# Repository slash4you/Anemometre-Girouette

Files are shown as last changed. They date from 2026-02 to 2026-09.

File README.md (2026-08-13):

# Anémomètre+Girouette
Projet de construction DIY d'un anémomètre et d‘ une girouette connectés à Home Assistant.

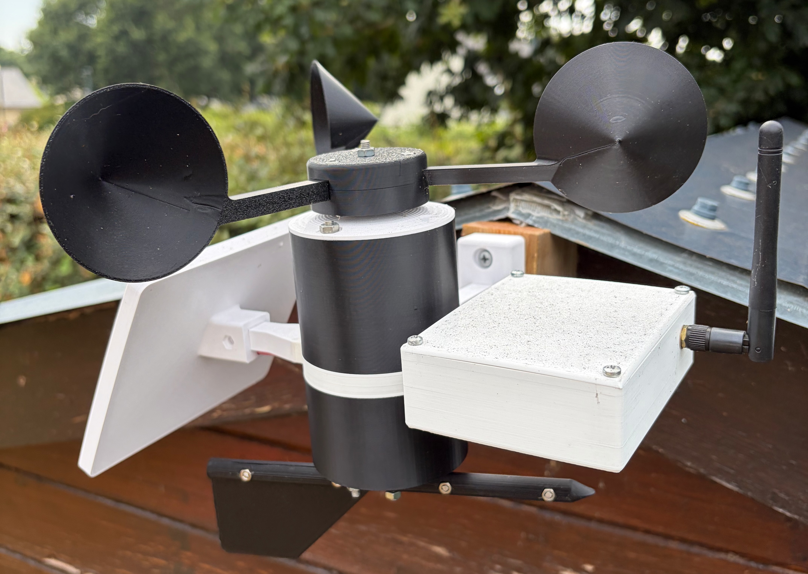
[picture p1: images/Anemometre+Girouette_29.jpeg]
Installation
 

## Caractéristiques principales 
|  | DIY | Conception |
|---|---|---|
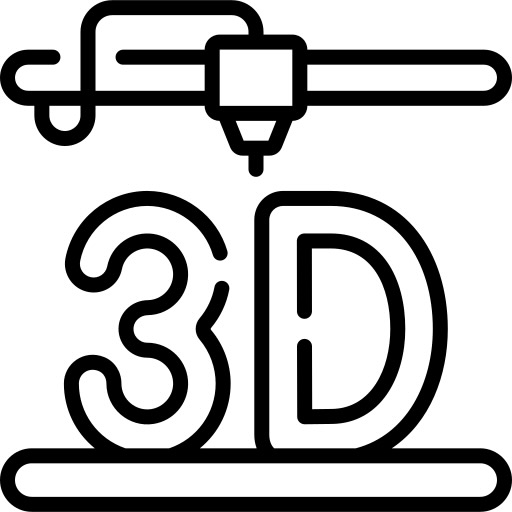
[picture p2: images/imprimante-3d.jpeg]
Imprimante 3D
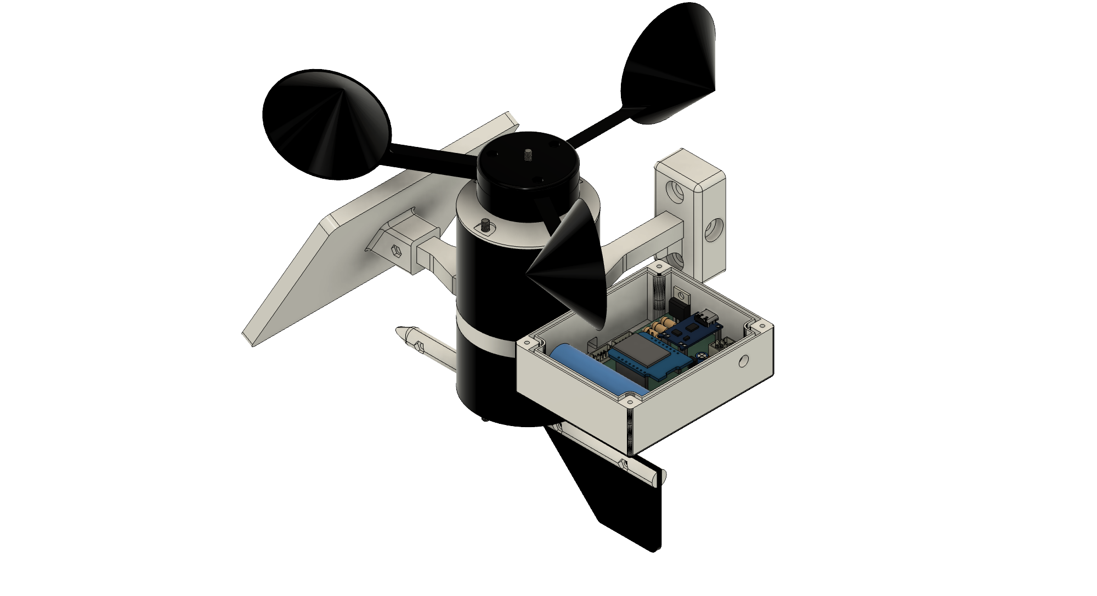
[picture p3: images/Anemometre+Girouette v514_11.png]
Modèle 3D
|  | 100% imprimable (PETG ou ABS, TPU), compacte, alimentation par batterie 18650 au Lithium (3800mAh) , recharge par panneau solaire (2W), mesure de la vitesse du vent par capteur à effet hall, mesure de la direction du vent (en cours)  |   |
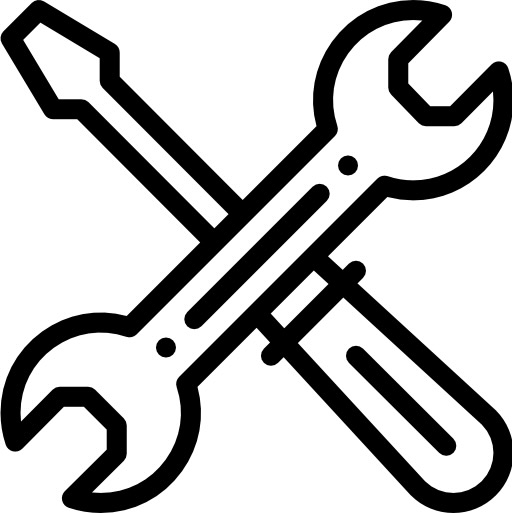
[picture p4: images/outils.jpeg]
Outils
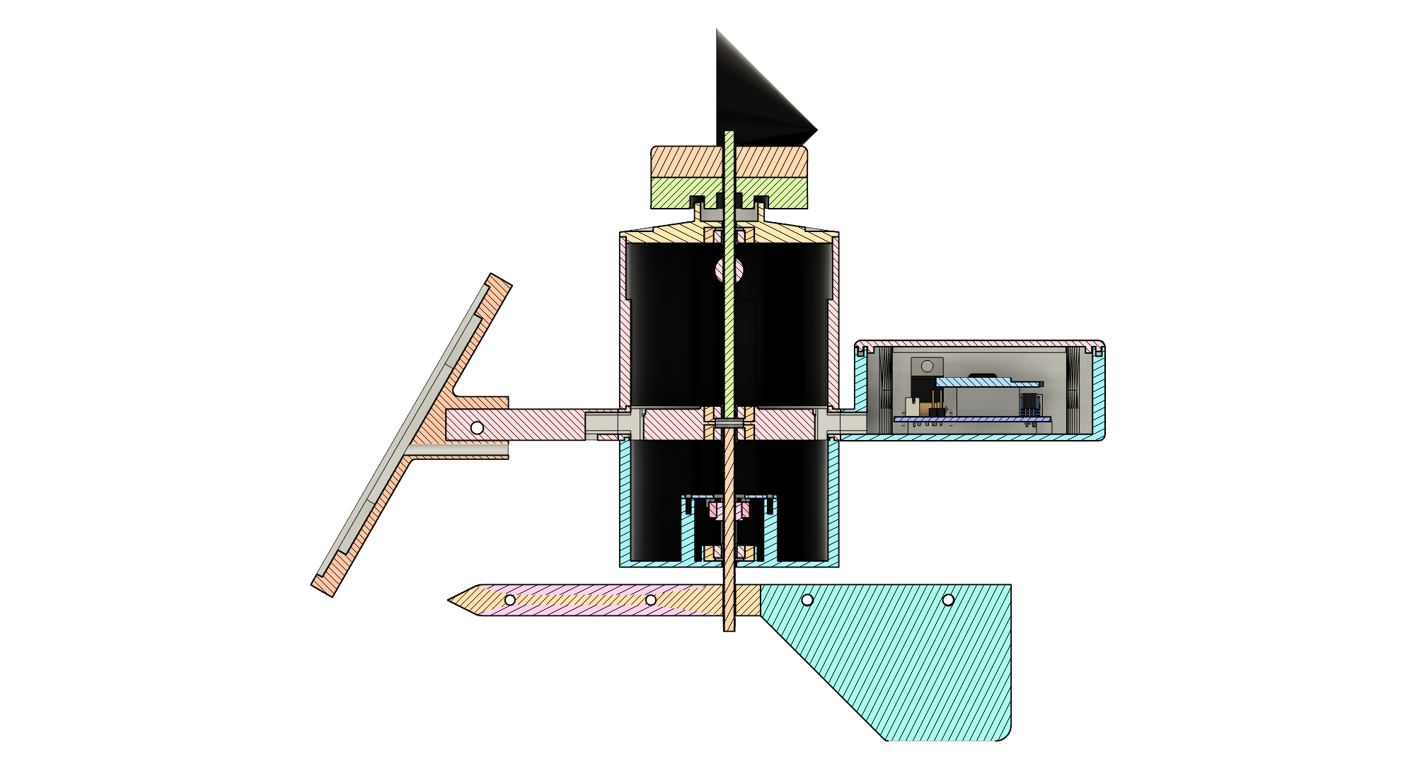
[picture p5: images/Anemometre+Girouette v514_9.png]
Modèle 2D
|  | assemblage par visserie standard, colle au silicone (étanchéité de la boite de commande), colle cyanoacrylate (selon l‘ ajustement des queues d‘ arronde) |   |
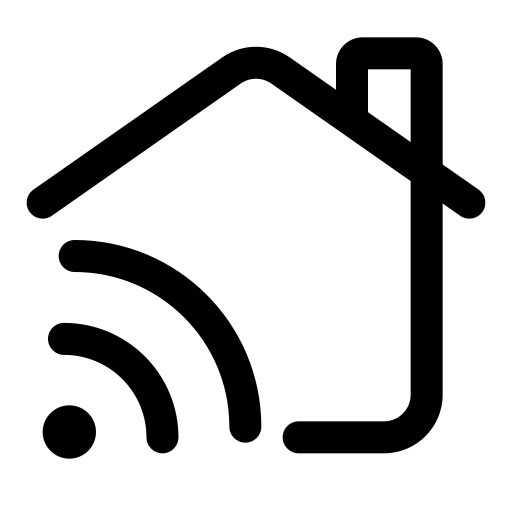
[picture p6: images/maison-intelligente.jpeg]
Domotique
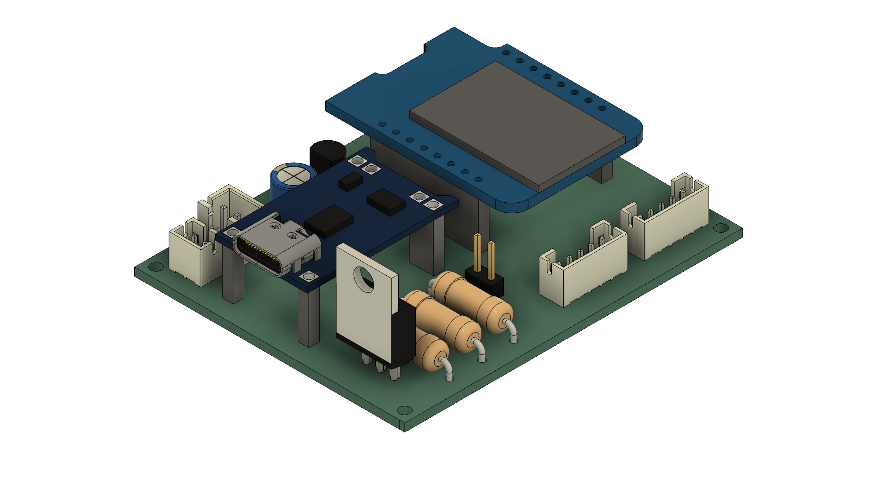
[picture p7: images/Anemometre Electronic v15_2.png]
|  | composants low-cost, firmware opensource, connection WIFI au serveur domotique, esphome ready, optimisation de l‘ autonomie |   |
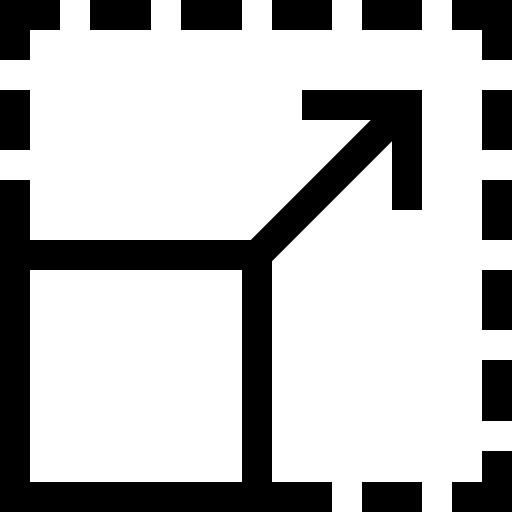
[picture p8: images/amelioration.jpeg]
Evolution
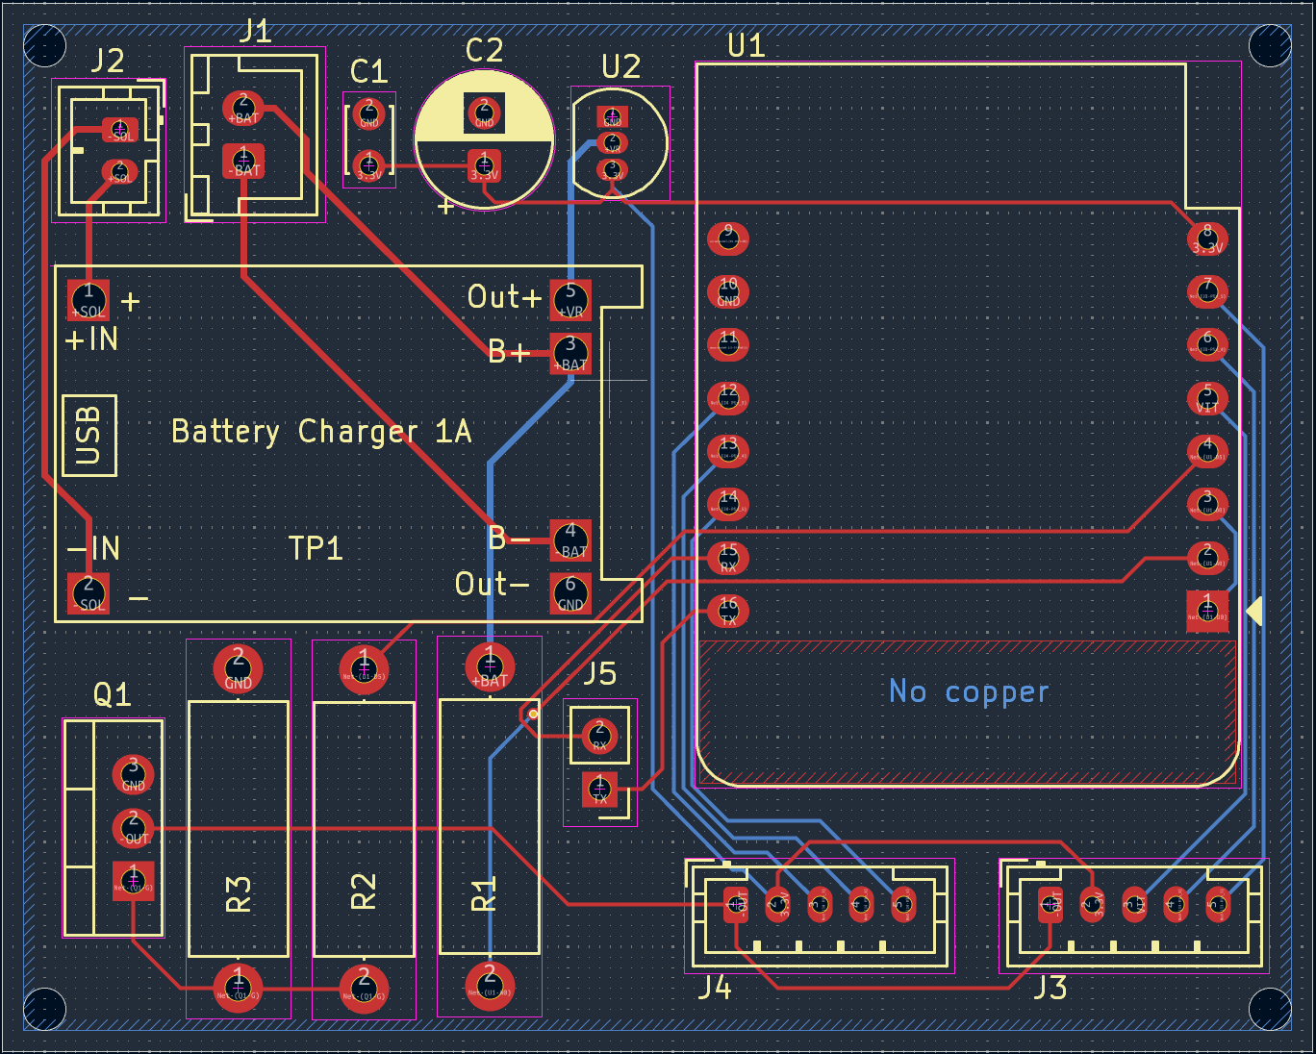
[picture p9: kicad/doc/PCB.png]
PCB
|  | conception modifiable, évolutive, toutes les données partagées, personnalisable à volonté |   |

## GitHub

Ce dépôt regroupe l‘ ensemble des données nécessaires à la construction de cet anémomètre, organisées de la façon suivante:
+ [fusion360](https://github.com/slash4you/Anemometre-Girouette/blob/main/fusion360) → contient le modèle 3D au format f3d
+ [bambustudio](https://github.com/slash4you/Anemometre-Girouette/blob/main/bambustudio) → contient le modèle d ‘impression au format 3mf
+ [stl](https://github.com/slash4you/Anemometre-Girouette/blob/main/stl) → contient le fichier de maillage de chaque composant au format stl
+ [esphome](https://github.com/slash4you/Anemometre-Girouette/blob/main/esphome) → contient la description du firmware au format yaml
+ [images](https://github.com/slash4you/Anemometre-Girouette/blob/main/images) → contient un ensemble d ‘ images du modèle et photos du prototype
+ [kicad](https://github.com/slash4you/Anemometre-Girouette/blob/main/kicad)  → contient la définition du PCB au format kicad et gerber

## Makerworld

Le projet d‘ impression correspondant est disponible ici:  [Anémomètre+Girouette](https://makerworld.com/fr/models/2154241) .

## Avancement

Le premier objectif est la mise au point d‘ un prototype fonctionnel (version beta du projet), avant de capitaliser les informations et formaliser la documentation indispensable à une diffusion plus large (version release du projet). 

> Pour les impatients sachez que ce n ‘est pas l‘ envie qui fait défaut mais bien le temps... d‘ autant qu‘ il s‘ agit de ma première expérience en modélisation 3D, en conception de PCB, et que l‘ impression 3D est une expérience très récente. Toute aide est la bienvenue pour corriger, améliorer, tester.. bref partager.

### 1. Version beta (V0) : prototypage

- [x] 100%  : modélisation de la structure mécanique
- [x] 100%  : approvisionnement des composants tierces
- [x] 100%  : impression+assemblage de la structure mécanique
- [x] 100%  : assemblage des composants électroniques ( panneau solaire + calculateur + batterie + CI )
- [x] 100%  : développement du firmware du calculateur
- [x] 100% : intégration des capteurs de mesure de l‘ anémomètre
- [x] 100% : 🍾
- [x] 100% : intégration des capteurs de mesure de la girouette
- [x] 100% : 🍾
- [x] 100% : tests en environnement réel
- [x] 100% : 🎉

| | Réalisation |
|---|---|
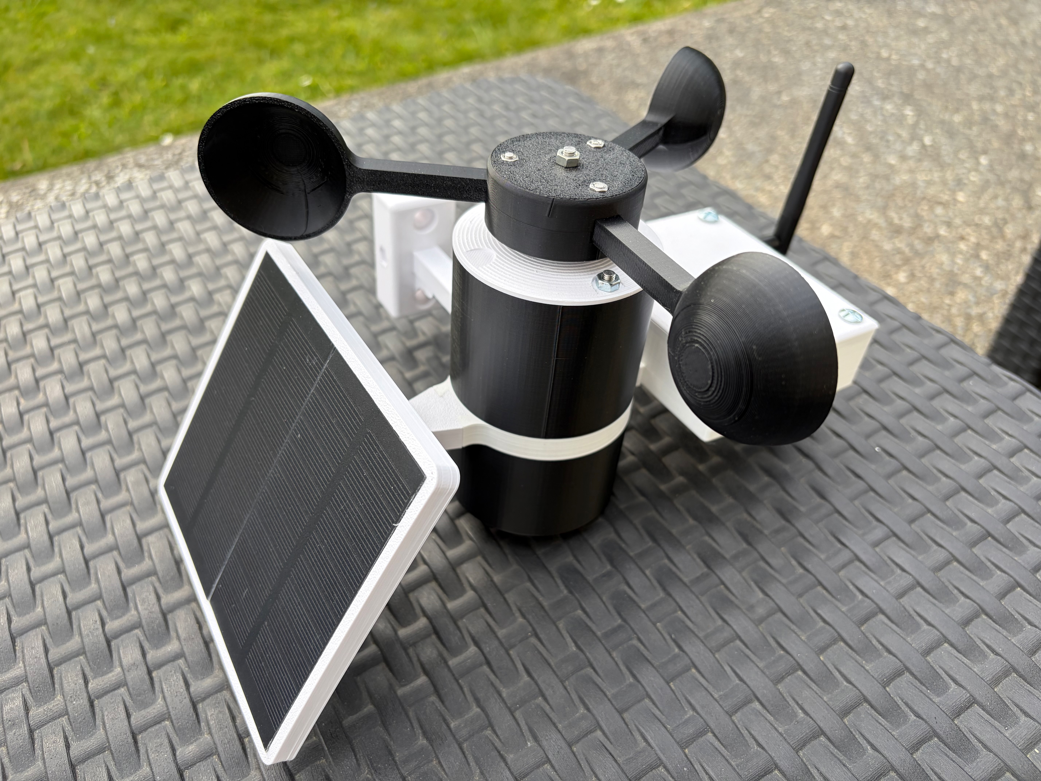
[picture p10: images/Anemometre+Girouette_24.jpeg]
Prototype
| Imprimante 3D |  |
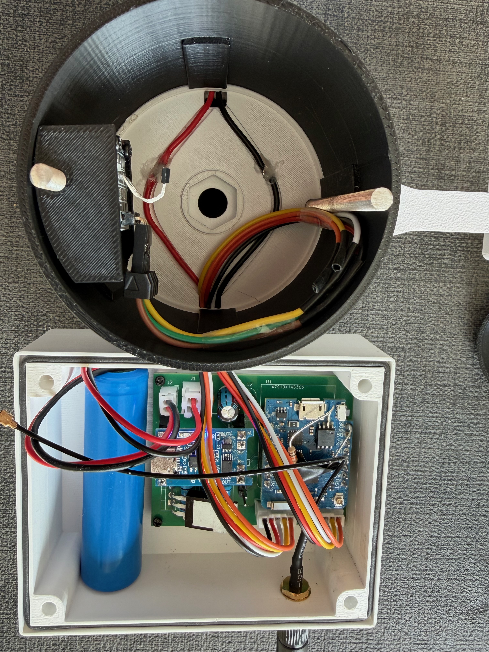
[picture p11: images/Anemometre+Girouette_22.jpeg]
Assemblage
| Outils |  |
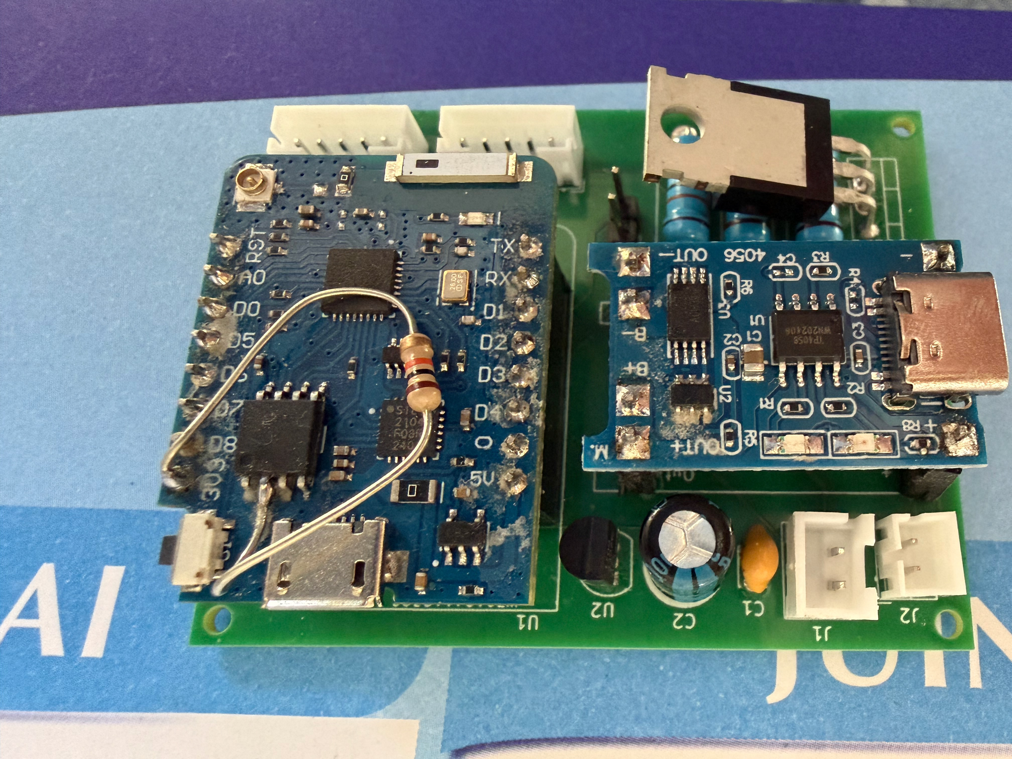
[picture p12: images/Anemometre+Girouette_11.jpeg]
| Domotique | |

### 2. Retours d‘ expérience sur le prototype après 1 mois

Après un mois d‘ installation dans le jardin, l‘ heure des premiers retours sur l‘ anémomètre DIY est arrivée :

#### Étanchéité de la boite de commande
Même si j‘ avais anticipé cette problématique lors de la conception, l‘ étanchéité du design initial n‘ était pas au rendez-vous puisqu‘ une semaine de pluie continue a complètement noyé la boite de commande. L‘ électronique et l‘ eau n‘ ont pas fait bon ménage et un des roulements s‘ est même oxydé jusqu‘ au blocage de la rotation de l‘ axe de l‘ anémomètre.
Une mise à jour de la boite de commande et de son couvercle a résolu ce problème.

#### Sensibilité par vent faible
J‘ avais privilégié la robustesse comme profil d‘ impression, craignant une fragilité des éléments imprimés lors des fortes rafale de vent assez fréquentes dans notre région. Mais je n‘ avais pas anticipé que l‘ inertie induite par cet excédent de matière aurait une conséquence sur la sensibilité par vent faible.
Une mise à jour de la forme et de la masse des coupelles a légèrement amélioré ce point mais l‘ inertie devra encore être optimisée et les frottements lors de la rotation devront être diminués pour obtenir un résultat convenable.
En l‘ état les coupelles se mettent en mouvement à partir de 10km/h de vent environ. Ceci se visualise parfaitement dans l‘ historisation des mesures par des tranches temporelles à 0 km/h car la période actuelle est très peu ventée ( vitesse moyenne locale issue d‘ internet comprise entre 5km/h et 15km/h.

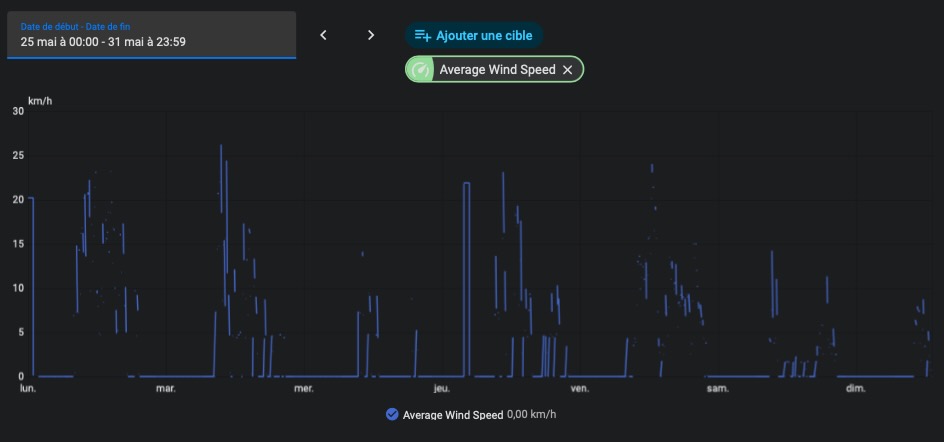
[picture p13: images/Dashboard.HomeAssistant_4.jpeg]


Parmi les axes d‘ amélioration :
* optimiser les dimensions et le taux de remplissage des éléments mobiles.
* améliorer le montage des roulements, voire le choix du nombre et du type de roulements pour limiter les frottements à la rotation.

#### Calibration RPM vs km/h
J‘ avais sous-estimé la problématique de calibration pour obtenir une estimation fiable de la vitesse du vent à partir de la vitesse de rotation de l‘ anémomètre. Cette problématique est d‘ autant plus exagérée dans mon cas que :
- le seul site d‘ installation dans mon jardin est trop protégé des vents.
- je suspecte que la compacité souhaitée pour cet anémomètre n‘ est pas idéal pour obtenir un flux d‘ air « laminaire », ou à minima le moins perturbé possible, indispensable pour des mesures fiables.

Pour l‘ instant je compense ceci par une table de calibration qui maximise exagérément les mesures, mais cette technique n‘ est pas viable pour un résultat convenable et surtout pas transposable pour quiconque utiliserait le firmware dans son contexte.

Monitoring

#### Électronique
L‘ électronique, et en particulier la gestion de l‘ énergie, sont en revanche une bonne surprise du projet. 
La stabilité de la communication avec le serveur domotique est au rendez-vous et la gestion de la charge de la batterie par le panneau solaire donne des résultats qui confirme la viabilité de la solution. 
Ce constat n‘ est sans doute pas étranger au fait que cette activité du projet est dans mes compétences.

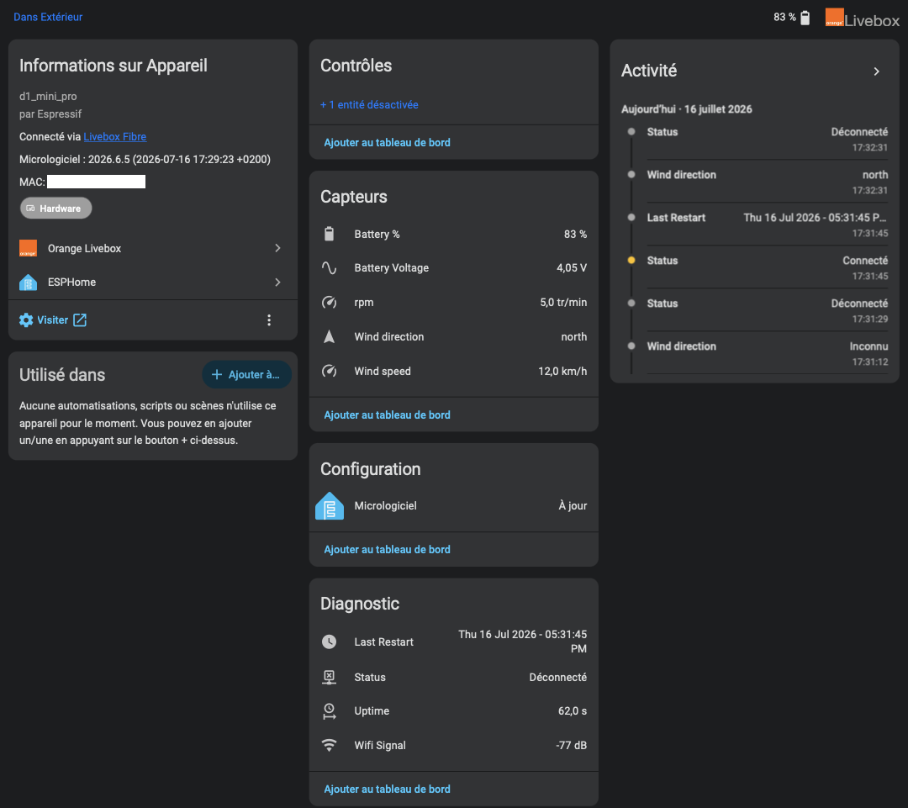
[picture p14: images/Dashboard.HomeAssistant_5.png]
Dashboard
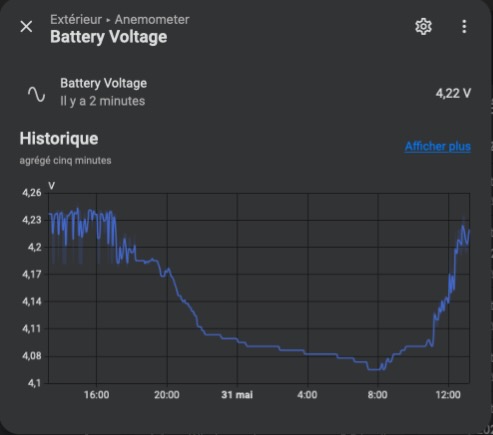
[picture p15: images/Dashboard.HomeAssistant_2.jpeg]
      

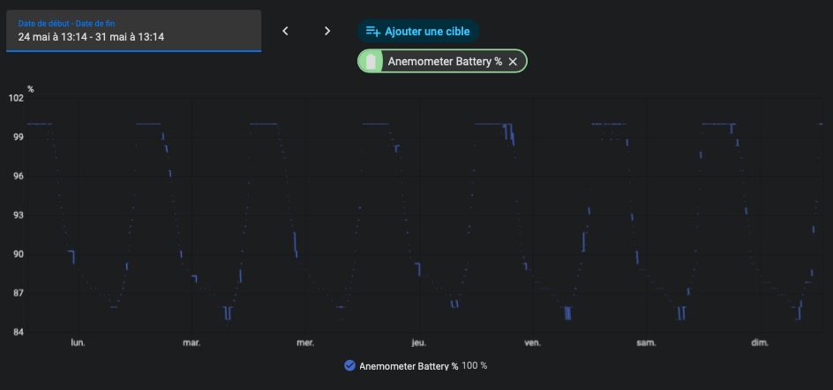
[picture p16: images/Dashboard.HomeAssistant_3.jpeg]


#### Assemblage
La complexité de l‘ assemblage révèle mon inexpérience en matière de conception 3D. Il est évident que le montage pourrait être largement simplifié par une meilleure conception, le nombre de pièces et le volume de matière imprimable pourraient être rationalisés, et par conséquent le coût global de la solution optimisé.
Parmi les axes d‘ amélioration :
* simplifier le montage des roulements pour limiter le nombre de pièces, la nécessité d‘ un parallélisme entre-eux, ...
* rendre indépendant la fixation du corps de la girouette de celle de l‘ anémomètre.
* utiliser un matériau transparent pour certaines pièces.

### 3. Retours d‘ expérience sur le prototype après 3 mois

Après trois mois d‘ installation dans le jardin, de nouvelles conclusions s‘ imposent :

#### Sensibilité par vent faible

La sensibilité de l‘ anémomètre a grandement été améliorée par un ajustement non contraint de l‘ un des 2 paliers de roulement pour chaque axe, libérant les contraintes axiales et contribuant ainsi à :
* simplifier globalement l‘ assemblage : moins de précision nécessaire au réglage de la longueur entre roulements,  fermeture facilitée par une insertion de l‘ extrémité opposée plus libre.
* augmenter de façon significative la sensibilité par vent faible, jusqu‘ à atteindre la vitesse de marche, soit environ 5 km/h.
Je considère que la mise à jour de ces ajustements a complètement résolu ce problème.

#### Pas de codage de la mesure de direction

J‘ envisageais initialement une conception permettant la mesure de 8 directions par la girouette, mais le prix unitaire pour coder 8 pas m‘ a semblé disproportionné. J‘ ai donc réduit cette spécification à 4 directions seulement pour limiter le coût global de la solution.

#### Stabilité de fonctionnement

Le montage est finalement achevé et fonctionnel, et la stabilité de fonctionnement sur la période est plus que satisfaisante. Un seul bug a été observé en 3 mois d‘ utilisation, nécessitant un reboot manuel du microcontrôleur pour palier à une absence de réveil (i.e. sortie du deep-sleep). Je n‘ ai pas beaucoup d‘ informations pour en analyser la cause car le problème est apparu au milieu de la nuit et avec toutes les traces logicielles désactivées. Mais je ne pense pas que le hardware soit en cause.  
A ce stade je mets plutôt en doute un problème introduit par une mise à jour d‘ esphome qui a souvent évolué sur la période et de manière significative.

#### Précisions des mesures

En toute transparence la précision des mesures est en-deçà de ce que j‘ espérais initialement. Un travail supplémentaire devra être mené sur :
* le site d‘ installation (problème spécifique à mon contexte)
* la calibration des mesures de vitesse de vent
* le lissage de la direction du vent par intégration dans le temps

### 4. Retours d‘ expérience sur le prototype après 4 mois

#### Précisions des mesures

Pour améliorer la précision des mesures, une variante du support mural a été conçue pour diminuer les perturbations dans la circulation des masses d‘ air.

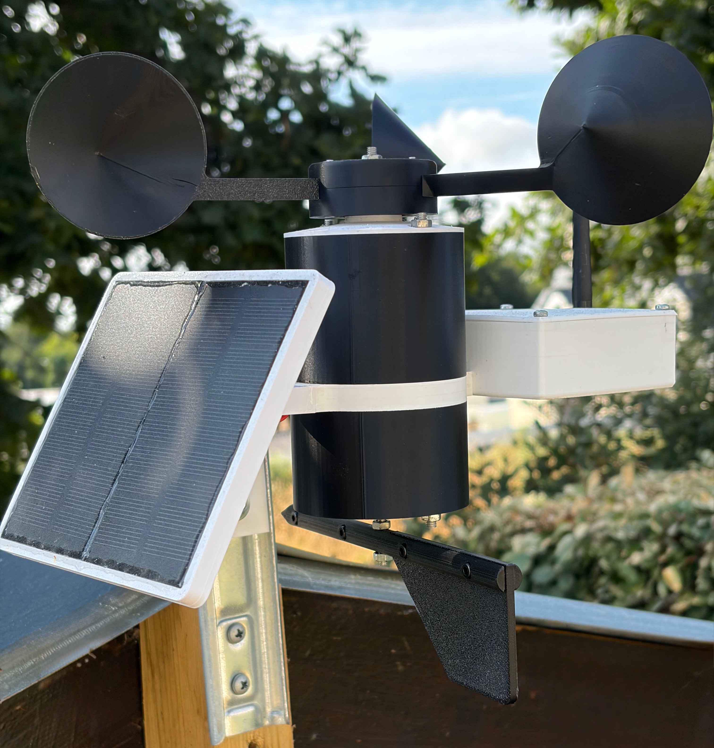
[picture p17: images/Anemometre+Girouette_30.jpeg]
Nouveau support
 

Ce nouveau support améliore un peu la précision des mesures, et en particulier la direction du vent, mais ne corrige pas le problème de fond de mon installation, la présence d‘ arbres à proximité dans toutes les directions .

### 5. Version release (V1) : partage et support

- [ ]    0%  : étalonnage des mesures et optimisation de leur durée d‘ intégration
- [ ]    0%  : optimisation de la charge en fonction de l‘ ensoleillement, de la saison, de l‘ heure, ...
- [ ]    0%  : publication d‘ un profil d‘ impression makerworld « plug-and-play »
- [x] 100%  : documentation/schéma électronique/inventaire des composants électroniques
- [ ]    0%  : documentation/inventaire des composants mécaniques
- [ ]    0%  : documentation/tutoriel de montage

#### Documentation

TODO

#### Inventaire des composants/matériaux

Pour quiconque se lancerait dans la construction, voici la liste des composants pour le PCB  :
| N° | Référence | Valeur/Modèle | Désignation |
|---|---|---|---|
| 1 | C1 | 100nF | [C_Disc_D3.0mm_W2.0mm_P2.50m](https://fr.aliexpress.com/item/32973259342.html) |
| 2 | C2 | 100µF | [CP_Radial_D6.3mm_P2.50mm](https://fr.aliexpress.com/item/1005002524973878.html) |
| 3 | R1 | 120KΩ | [R_Axial_DIN0414_L11.9mm_D4.5mm_P15.24mm_Horizontal](https://fr.aliexpress.com/item/1005007032692303.html) |
| 4 | R2 | 330Ω | [R_Axial_DIN0414_L11.9mm_D4.5mm_P15.24mm_Horizontal](https://fr.aliexpress.com/item/1005007032692303.html) |
| 5 | R3 | 120KΩ | [R_Axial_DIN0414_L11.9mm_D4.5mm_P15.24mm_Horizontal](https://fr.aliexpress.com/item/1005007032692303.html) |
| 6 | U1 | WeMos D1 mini pro | [WEMOS_D1_mini_light](https://fr.aliexpress.com/item/1005007475726143.html) |
| 7 | U2 | MCP1700-330 TO-92 | [TO-92_Inline](https://fr.aliexpress.com/item/1005007167297693.html) |
| 8 | Q1 | IRLZ44N TO-220 | [TO-220-3_Vertical](https://fr.aliexpress.com/item/1005007174659364.html) |
| 9 | TP1 | TP4056 USB-C | [TP4056_module](https://fr.aliexpress.com/item/1005006124994712.html) |
| 10 | J1 | XH2.54-2P | [JST_XH_B2B-XH-A_1x02_P2.50mm_Vertical](https://fr.aliexpress.com/item/1005004985397880.html) |
| 11 | J2 | PH2.0-2P | [JST_PH_B2B-PH-K_1x02_P2.00mm_Vertical](https://fr.aliexpress.com/item/1005007441813591.html) |
| 12 | J3 | PH2.0-5P | [JST_PH_B5B-PH-K_1x05_P2.00mm_Vertical](https://fr.aliexpress.com/item/1005007441813591.html) |
| 13 | J4 | PH2.0-5P | [JST_PH_B5B-PH-K_1x05_P2.00mm_Vertical](https://fr.aliexpress.com/item/1005007441813591.html) |
| 14 | J5 | XH2.54-2P | [PinHeader_1x02_P2.54mm_Vertical](https://fr.aliexpress.com/item/4000988113226.html) |

La liste des composants pour l‘ alimentation :
| N° | Qté | Valeur/Modèle | Désignation |
|---|---|---|---|
| 1 | 1| 18650 Lithium 3.7V 3800mAh XH2.54-2P | [Batterie Lithium](https://fr.aliexpress.com/item/1005007257546981.html)|
| 2 | 2| 5V 1W 107x61mm| [Panneaux solaires](https://fr.aliexpress.com/item/1005006711306491.html)|

La liste des composants pour les mesures :
| N° | Qté | Valeur/Modèle | Désignation |
|---|---|---|---|
|  1 | 1| KY-003 A3144| [Capteur à effet hall](https://fr.aliexpress.com/item/1005007985856987.html) |
|  2  | 2 | Disque 5x3mm | [Aimants ferrite](https://fr.aliexpress.com/item/1005008858265927.html) |
| 3  |  1 | STM8-P4 | [Capteur magnétique  de direction](https://fr.aliexpress.com/item/1005004379591016.html) |

La liste des consommables pour l‘ impression 3D :
| N° | Qté | Valeur/Modèle | Désignation |
|---|---|---|---|
|  1 | NNNg| PETG HF| [blanc](https://eu.store.bambulab.com/fr/products/petg-hf?id=49068714787164) |
|  2  | NNNg  | PETG HF  | [noir](https://eu.store.bambulab.com/fr/products/petg-hf?id=49068714754396) |
|  3  | NNNg  | TPU  | [noir](https://eu.store.bambulab.com/fr/products/tpu-95a-hf?id=47305218687324) |

La liste des consommables pour l‘ anémomètre :
| N° | Qté | Valeur/Modèle | Désignation |
|---|---|---|---|
|  1 | 2| M4x200| [Tiges filetées](https://fr.aliexpress.com/item/1005008105589322.html) |
|  2  | 4  | 5x10x4mm  | [Roulements](https://fr.aliexpress.com/item/1005007668446060.html) |
|  3  | N  | M4  | Ecrous |
| 4  | 4 | M3x30 | [Vis](https://fr.aliexpress.com/item/1005002011961287.html) |
| 5 | 4 | M3 | Ecrous |
| 6  | N | TODO | TODO |

## Licence

L e projet est publié sous licence [Creative Commons Attribution-Noncommercial-Share Alike](https://github.com/slash4you/Anemometre-Girouette/blob/main/LICENSE.md).



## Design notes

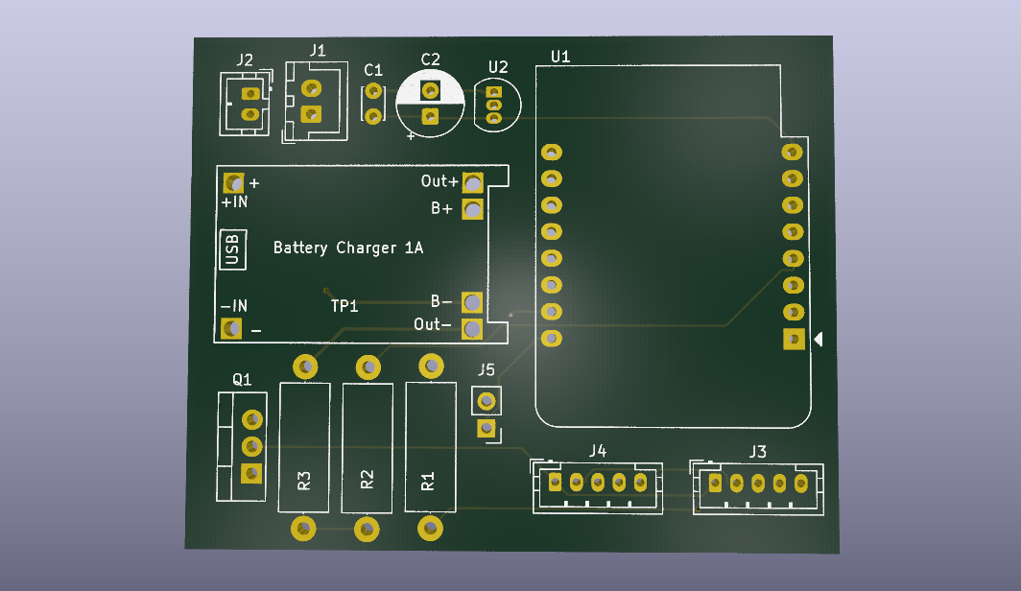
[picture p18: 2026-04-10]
kicad/doc/Electronic.png

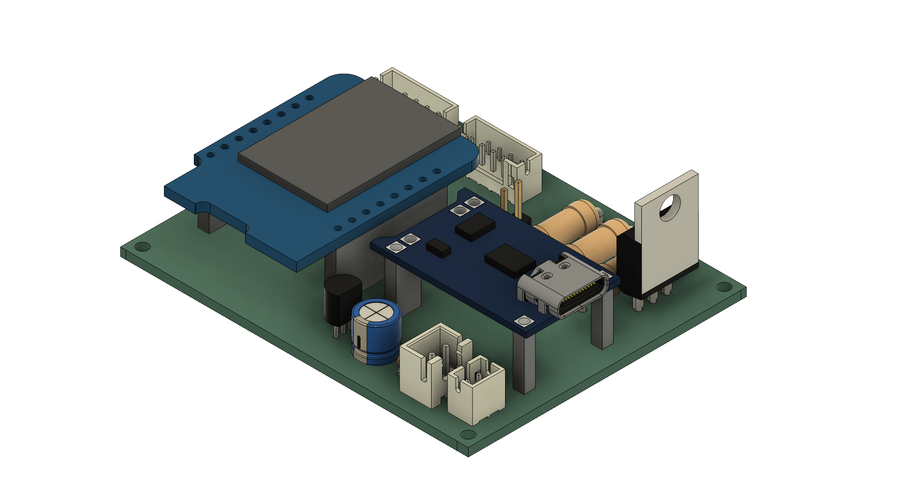
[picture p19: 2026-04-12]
images/Anemometre Electronic v15_3.png

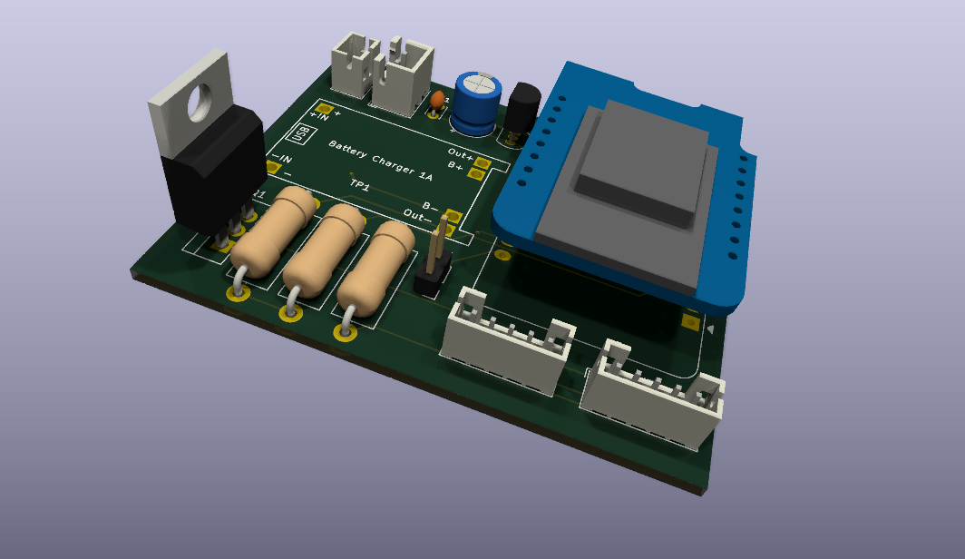
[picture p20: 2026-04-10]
kicad/doc/Electronic3D.png

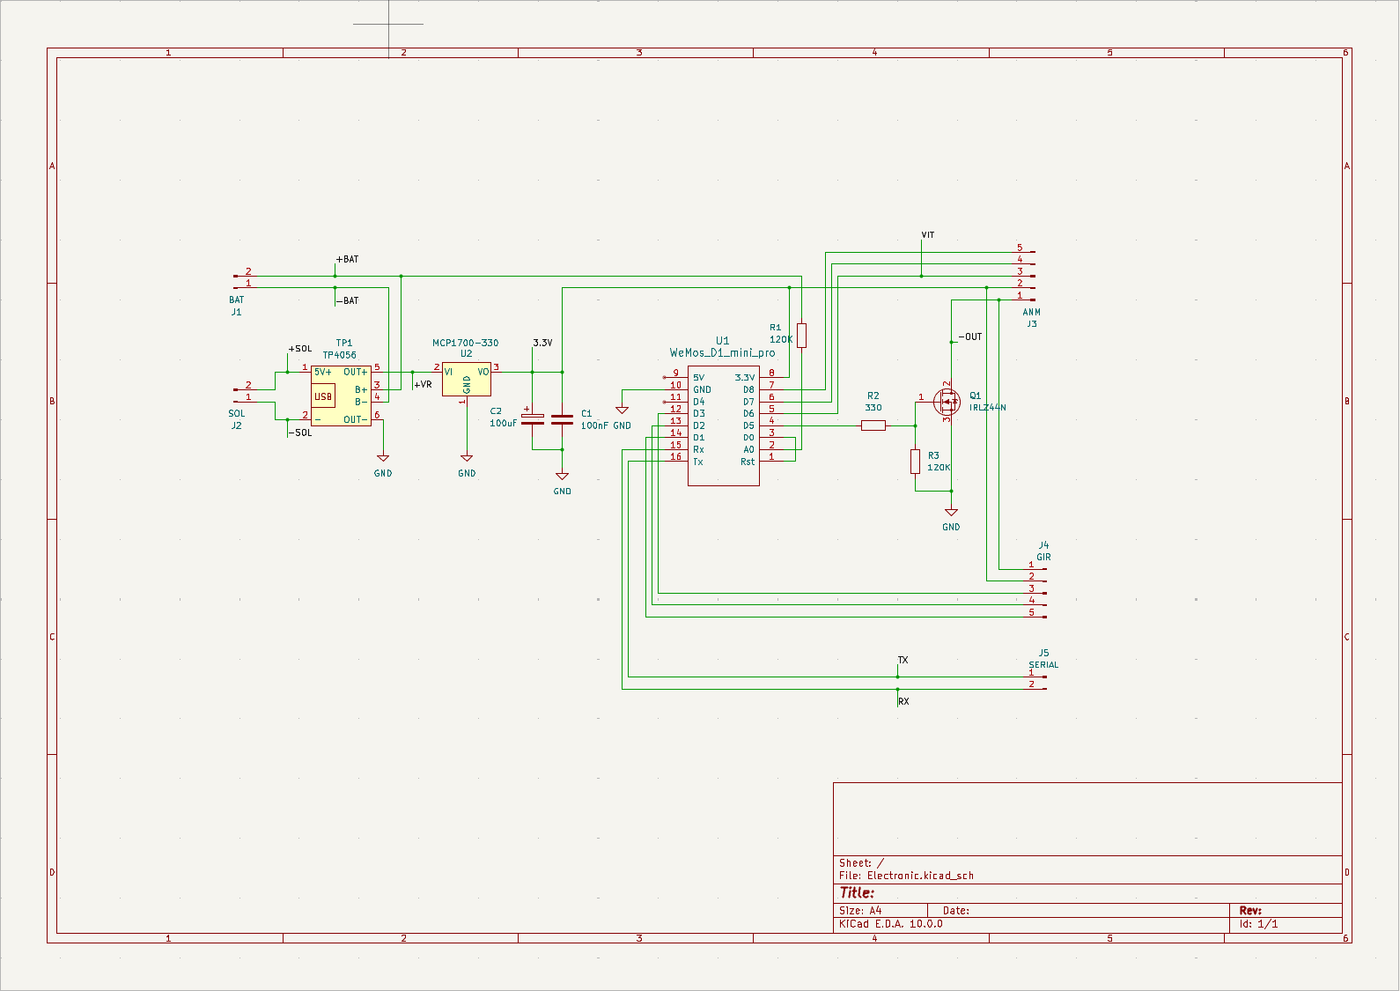
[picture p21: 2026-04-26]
kicad/doc/schematic.png

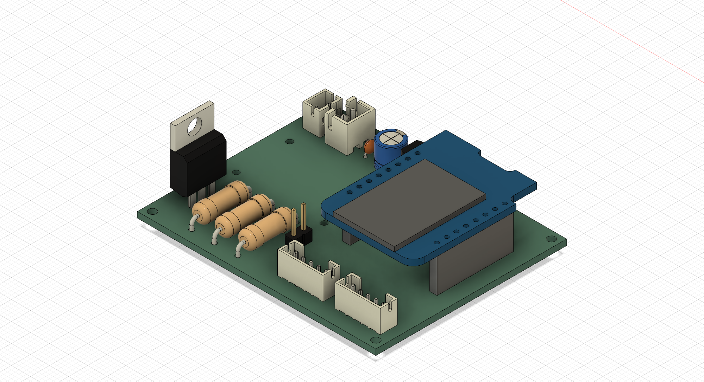
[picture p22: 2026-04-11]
images/Anemometre-Electronic v7.png

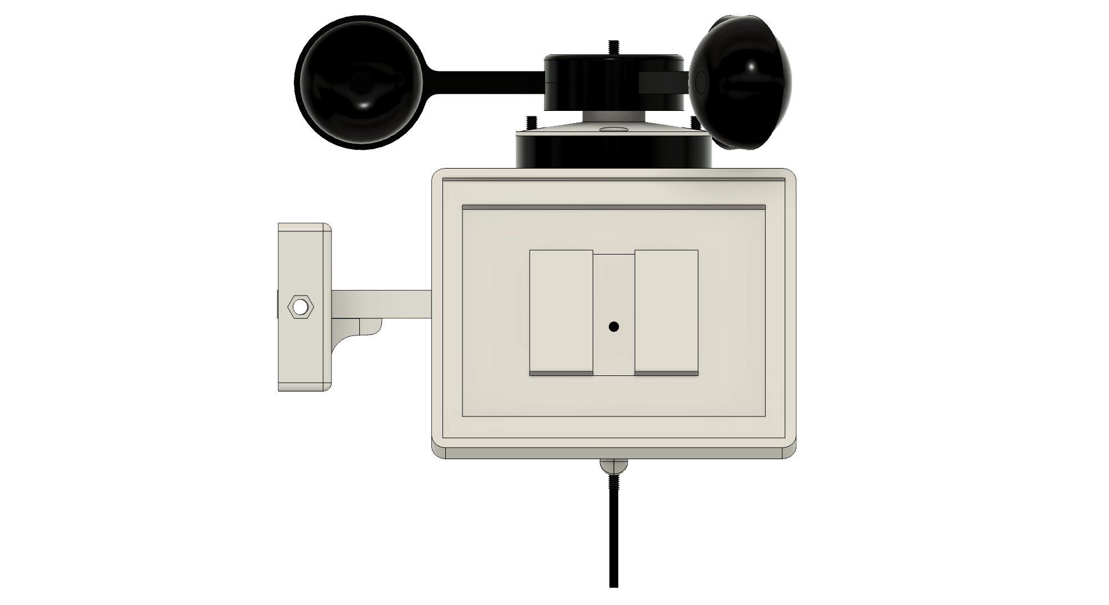
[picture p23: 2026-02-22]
images/Anemometre+Girouette v345_4.png

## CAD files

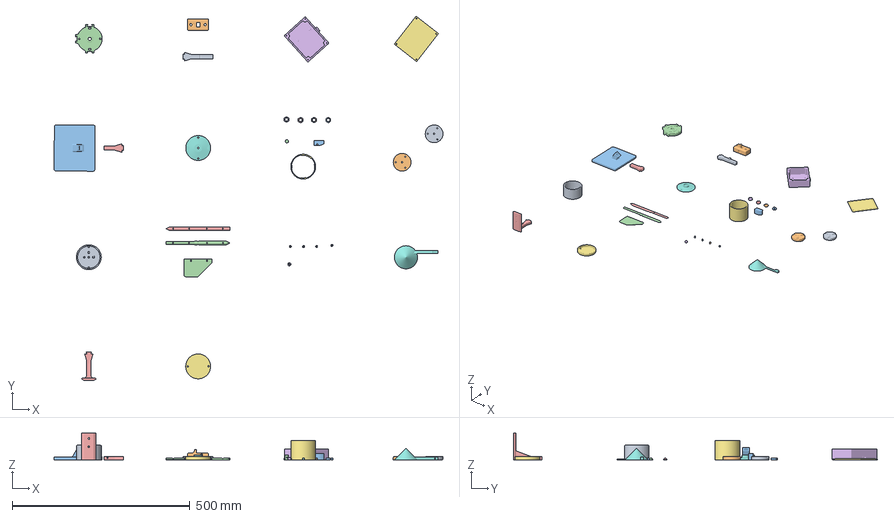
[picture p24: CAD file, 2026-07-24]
bambustudio/Anemometre+Girouette.3mf
1094.6 x 1024.8 x 75.0 mm
Liaison Mur.stl
Fixation murale.stl
Panneau solaire double fixe.stl
Girouette - Flèche.stl
Cage roulement.stl x 2
Anemometre - boitier.stl
Anemometre - Couvercle Sup.stl
Support Helice Sup.stl
Support Helice Inf.stl
Anemometre - Support US1881.stl
Anemometre - support aimants.stl
Liaison panneau solaire fixe.stl
Boite de commande - corps etanche.stl
Boite de commande - couvercle etanche.stl
Coupelle Conique.stl
Girouette - boitier.stl
Cage roulement libre.stl x 2
Girouette - Corps.stl
Girouette - Corps 2.stl
Girouette - Pallier Aimant.stl
Girouette - Variante.stl
Pallier roulement.stl x 4
Liaison Anémomètre.stl
Liaison Mur - Variante.stl

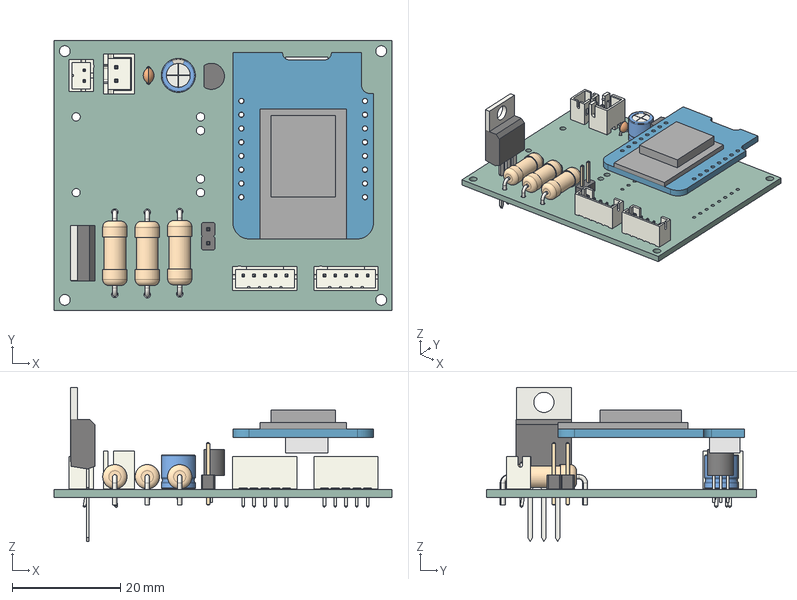
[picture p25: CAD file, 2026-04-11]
kicad/doc/electronic.step
62.5 x 50.0 x 28.5 mm
JST_PH_B2B-PH-K_1x02_P2.00mm_Vertical
CP_Radial_D6.3mm_P2.50mm
R_Axial_DIN0414_L11.9mm_D4.5mm_P15.24mm_Horizontal x 3
JST_XH_B2B-XH-A_1x02_P2.50mm_Vertical
WEMOS_D1_mini_light
TO-92_Inline
JST_PH_B5B-PH-K_1x05_P2.00mm_Vertical x 2
TO-220-3_Vertical
C_Disc_D3.0mm_W2.0mm_P2.50mm
PinHeader_1x02_P2.54mm_Vertical
Electronic_PCB

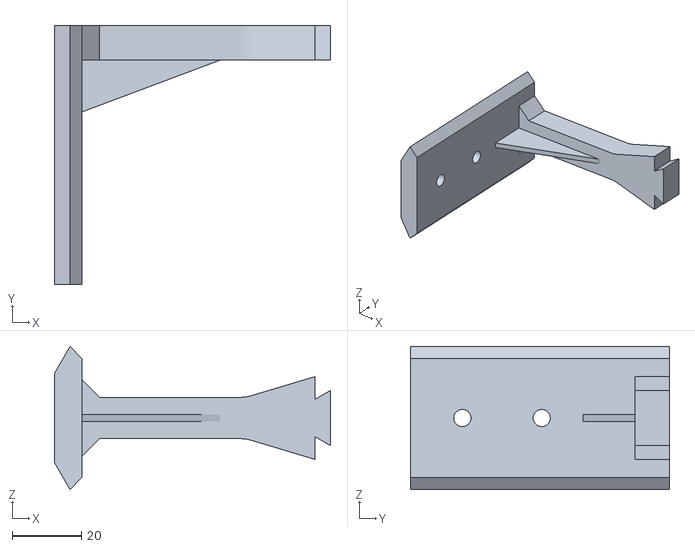
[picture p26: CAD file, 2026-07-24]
stl/Liaison Mur - Variante.stl
80.0 x 75.0 x 41.5

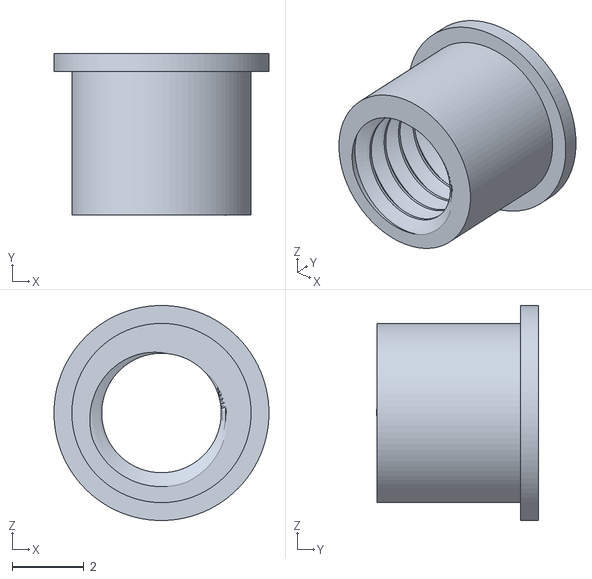
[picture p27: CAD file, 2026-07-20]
stl/Pallier roulement.stl
6.00 x 4.52 x 6.00

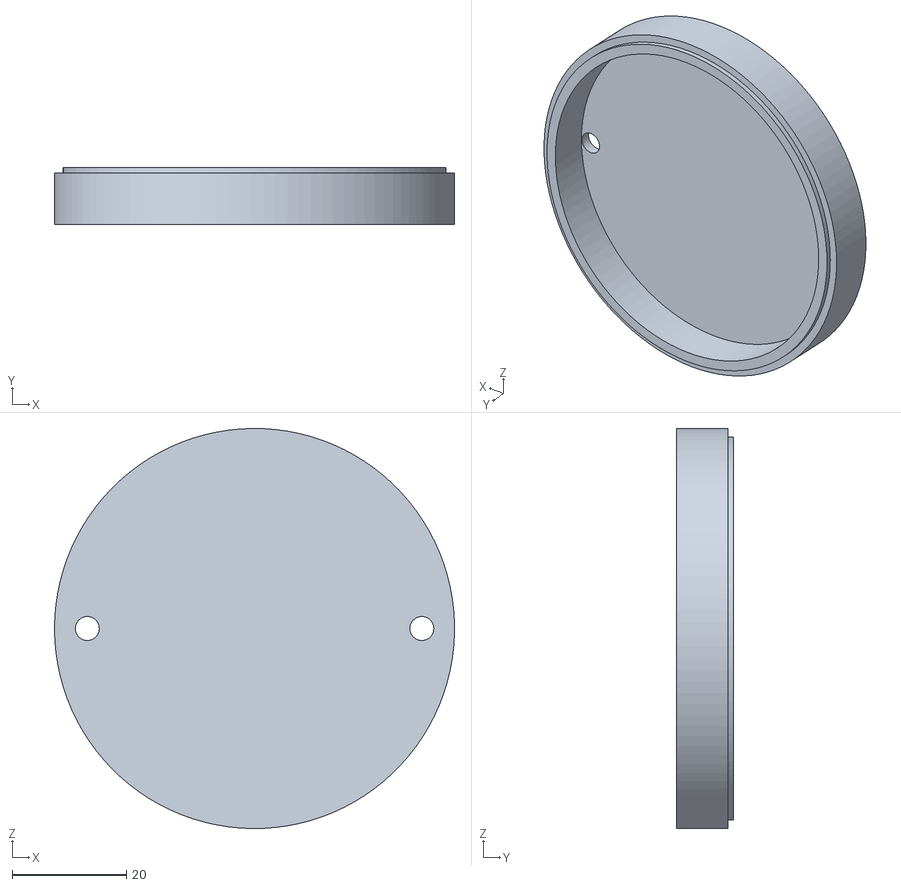
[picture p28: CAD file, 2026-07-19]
stl/Girouette - Variante.stl
70.0 x 10.0 x 70.0

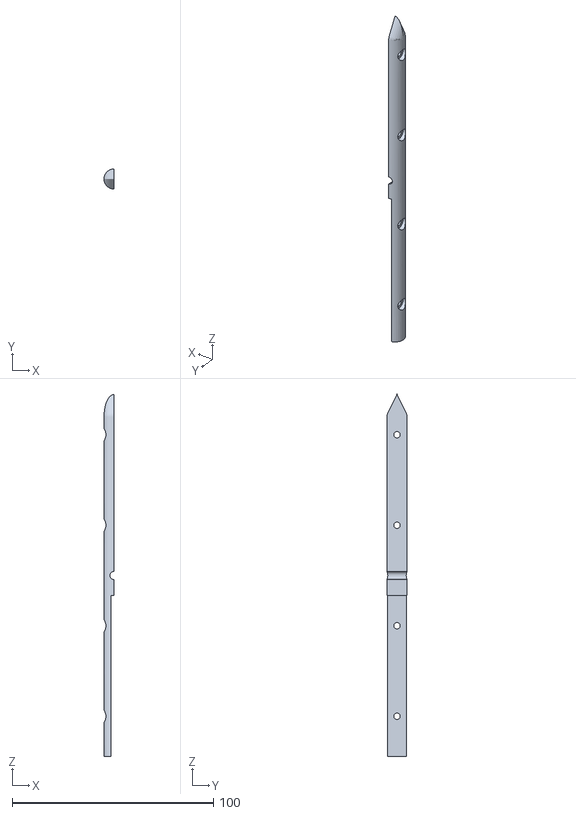
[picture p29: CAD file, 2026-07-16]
stl/Girouette - Corps.stl
5.00 x 10.0 x 180.0

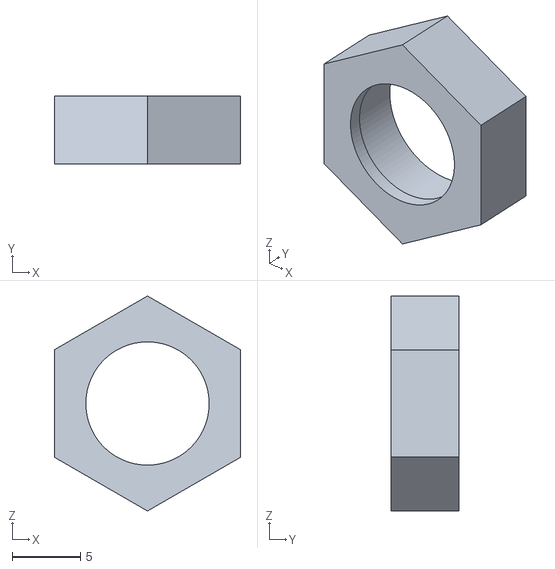
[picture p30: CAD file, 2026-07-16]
stl/Cage roulement libre.stl
13.6 x 5.00 x 15.7

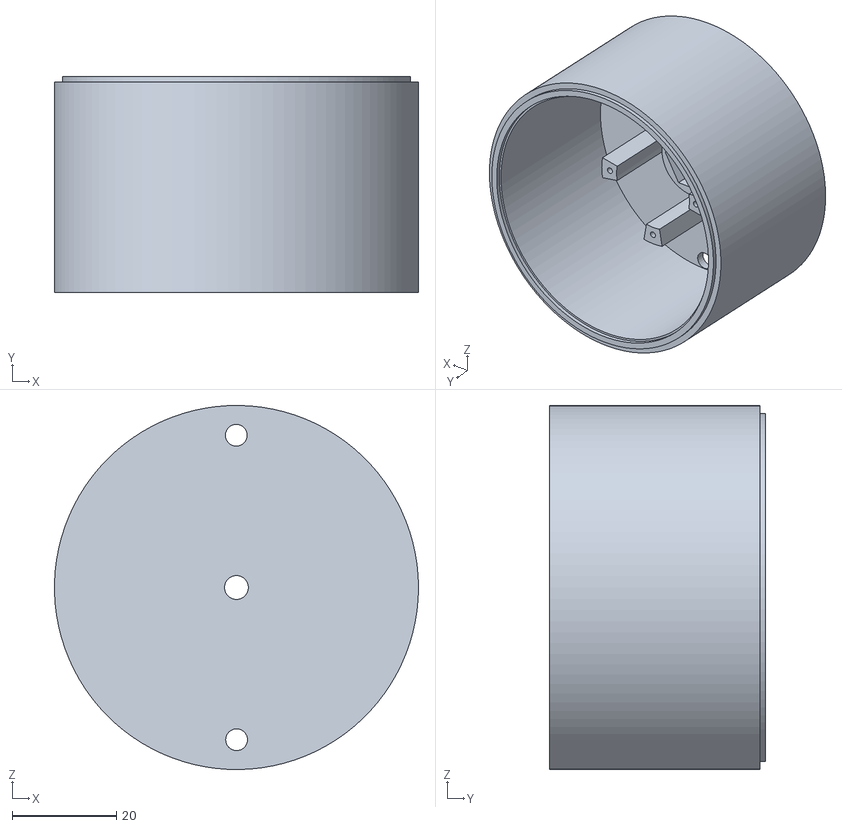
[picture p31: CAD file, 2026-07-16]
stl/Girouette - boitier.stl
70.0 x 41.5 x 70.0

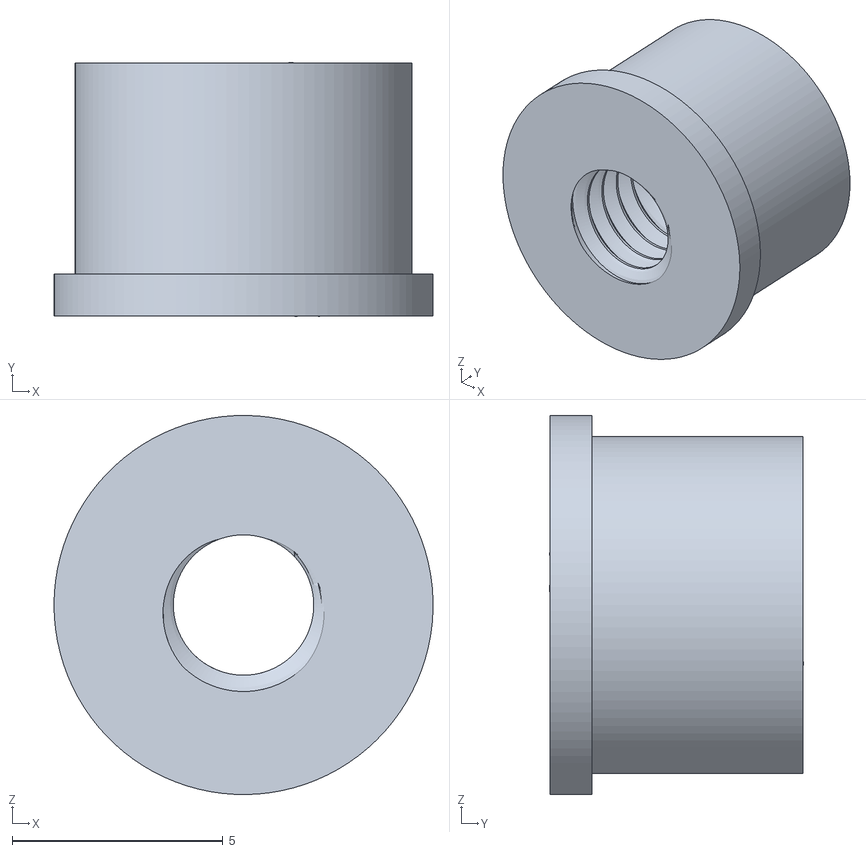
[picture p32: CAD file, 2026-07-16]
stl/Girouette - Pallier Aimant.stl
9.00 x 6.03 x 9.00

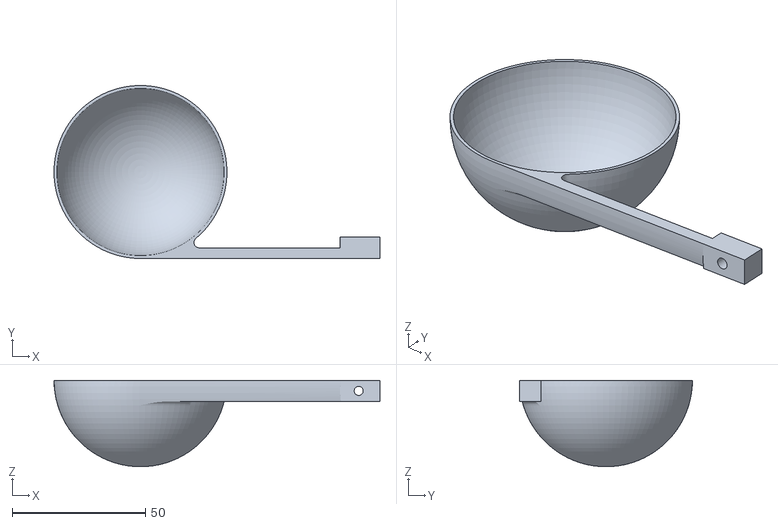
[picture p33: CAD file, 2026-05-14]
stl/Coupelle Spherique.stl
122.5 x 65.0 x 32.5

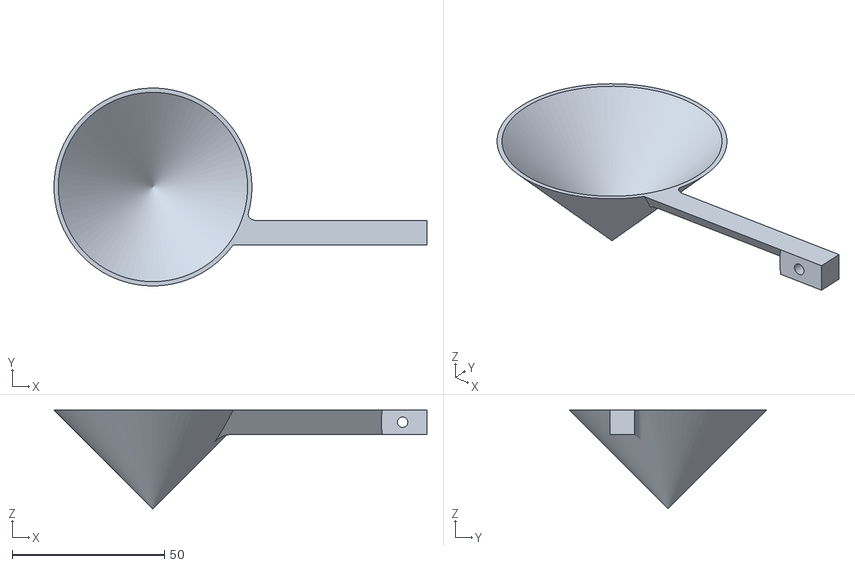
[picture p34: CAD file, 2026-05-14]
stl/Coupelle Conique.stl
122.5 x 65.0 x 32.5

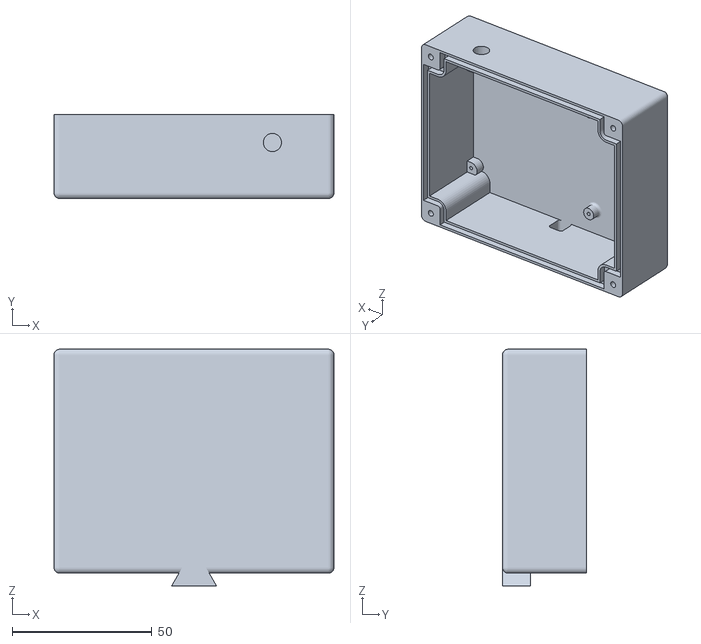
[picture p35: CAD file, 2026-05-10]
stl/Boite de commande - corps etanche.stl
100.0 x 30.0 x 84.5

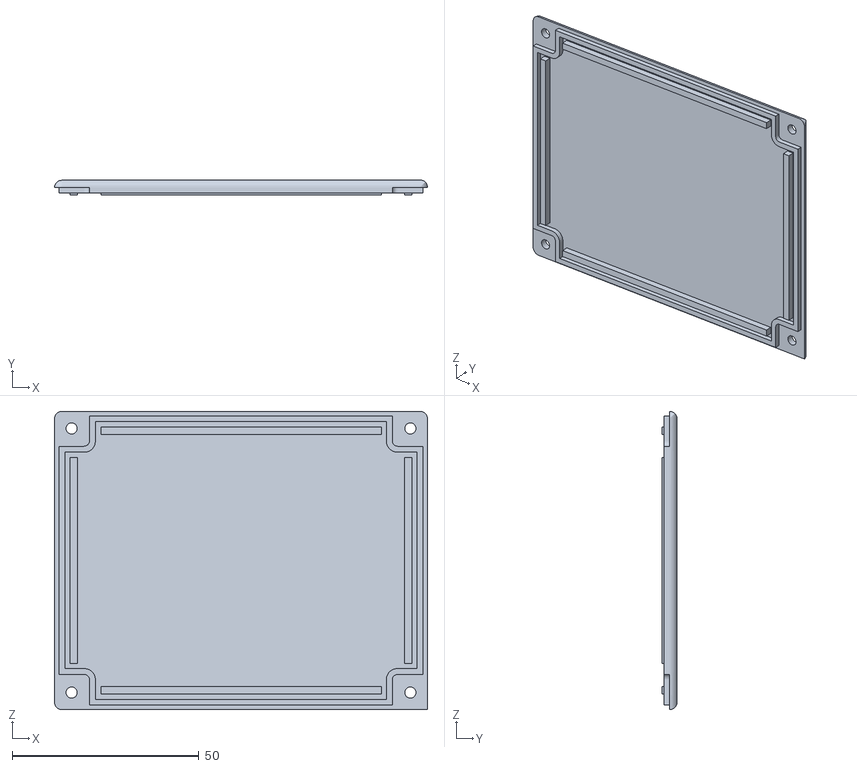
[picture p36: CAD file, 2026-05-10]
stl/Boite de commande - couvercle etanche.stl
100.0 x 4.07 x 80.0

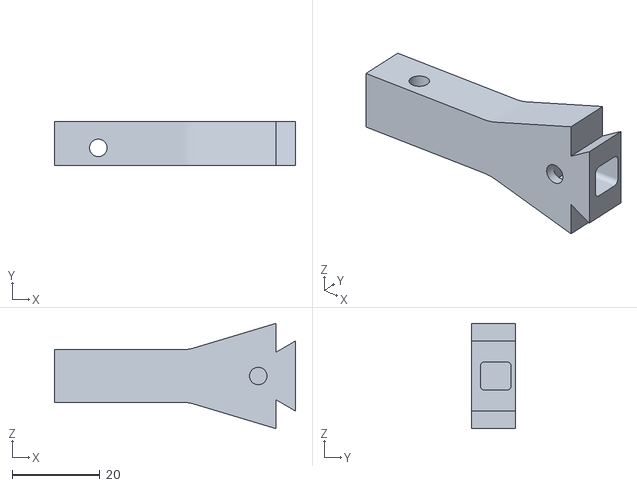
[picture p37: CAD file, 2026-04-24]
stl/Liaison panneau solaire fixe.stl
55.0 x 10.0 x 24.0

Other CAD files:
stl/Girouette - Corps 2.stl
stl/Liaison Anémomètre.stl
stl/Anemometre - boitier.stl
stl/Anemometre - Support US1881.stl
fusion360/parts/Anemometre-Electronic.f3d
stl/Anemometre - Axe Etalon.stl
stl/Anemometre - Couvercle Sup.stl
stl/Anemometre - support aimants.stl
stl/Cage roulement.stl
stl/Fixation murale.stl
stl/Girouette - Axe Etalon.stl
stl/Girouette - Flèche.stl
stl/Helice.stl
stl/Liaison Mur.stl
stl/Panneau solaire double fixe.stl
stl/Roulement.stl
stl/Support Helice Inf.stl
stl/Support Helice Sup.stl

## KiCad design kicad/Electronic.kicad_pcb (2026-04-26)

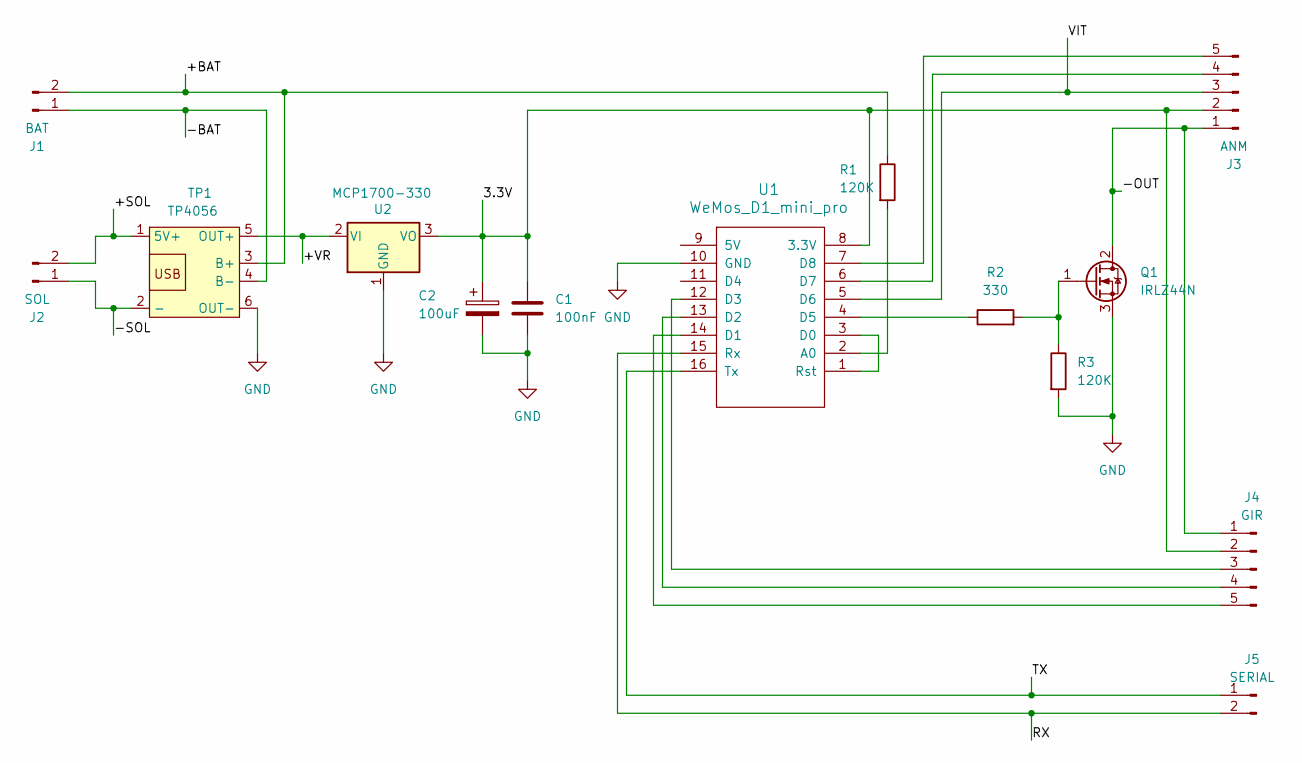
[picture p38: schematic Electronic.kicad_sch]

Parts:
C1: 100nF; C_Disc_D3.0mm_W2.0mm_P2.50mm
C2: 100uF; CP_Radial_D6.3mm_P2.50mm
J1: BAT; JST_XH_B2B-XH-A_1x02_P2.50mm_Vertical
J2: SOL; JST_PH_B2B-PH-K_1x02_P2.00mm_Vertical
J3: ANM; JST_PH_B5B-PH-K_1x05_P2.00mm_Vertical
J4: GIR; JST_PH_B5B-PH-K_1x05_P2.00mm_Vertical
J5: SERIAL; PinHeader_1x02_P2.54mm_Vertical
Q1: IRLZ44N; TO-220-3_Vertical
R1, R3: 120K; R_Axial_DIN0414_L11.9mm_D4.5mm_P15.24mm_Horizontal
R2: 330; R_Axial_DIN0414_L11.9mm_D4.5mm_P15.24mm_Horizontal
TP1: TP4056; TP4056_module
U1: WeMos_D1_mini_pro; WEMOS_D1_mini_light
U2: MCP1700-330; TO-92_Inline

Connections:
/3.3V: C1.1, C2.1, J3.2, J4.2, U1.8 (3.3V), U2.3 (VO)
/+BAT: J1.2, R1.1, TP1.3 (B+)
/+SOL: J2.2, TP1.1 (5V+)
/+VR: TP1.5 (OUT+), U2.2 (VI)
/-BAT: J1.1, TP1.4 (B-)
/-OUT: J3.1, J4.1, Q1.2 (D)
/-SOL: J2.1, TP1.2 (-)
/RX: J5.2, U1.15 (Rx)
/TX: J5.1, U1.16 (Tx)
/VIT: J3.3, U1.5 (D6)
GND: C1.2, C2.2, Q1.3 (S), R3.2, TP1.6 (OUT-), U1.10 (GND), U2.1 (GND)
unnamed: J3.4, U1.6 (D7)
unnamed: J3.5, U1.7 (D8)
unnamed: J4.3, U1.12 (D3)
unnamed: J4.4, U1.13 (D2)
unnamed: J4.5, U1.14 (D1)
unnamed: Q1.1 (G), R2.2, R3.1
unnamed: R1.2, U1.2 (A0)
unnamed: U1.1 (Rst), U1.3 (D0)
unnamed: R2.1, U1.4 (D5)

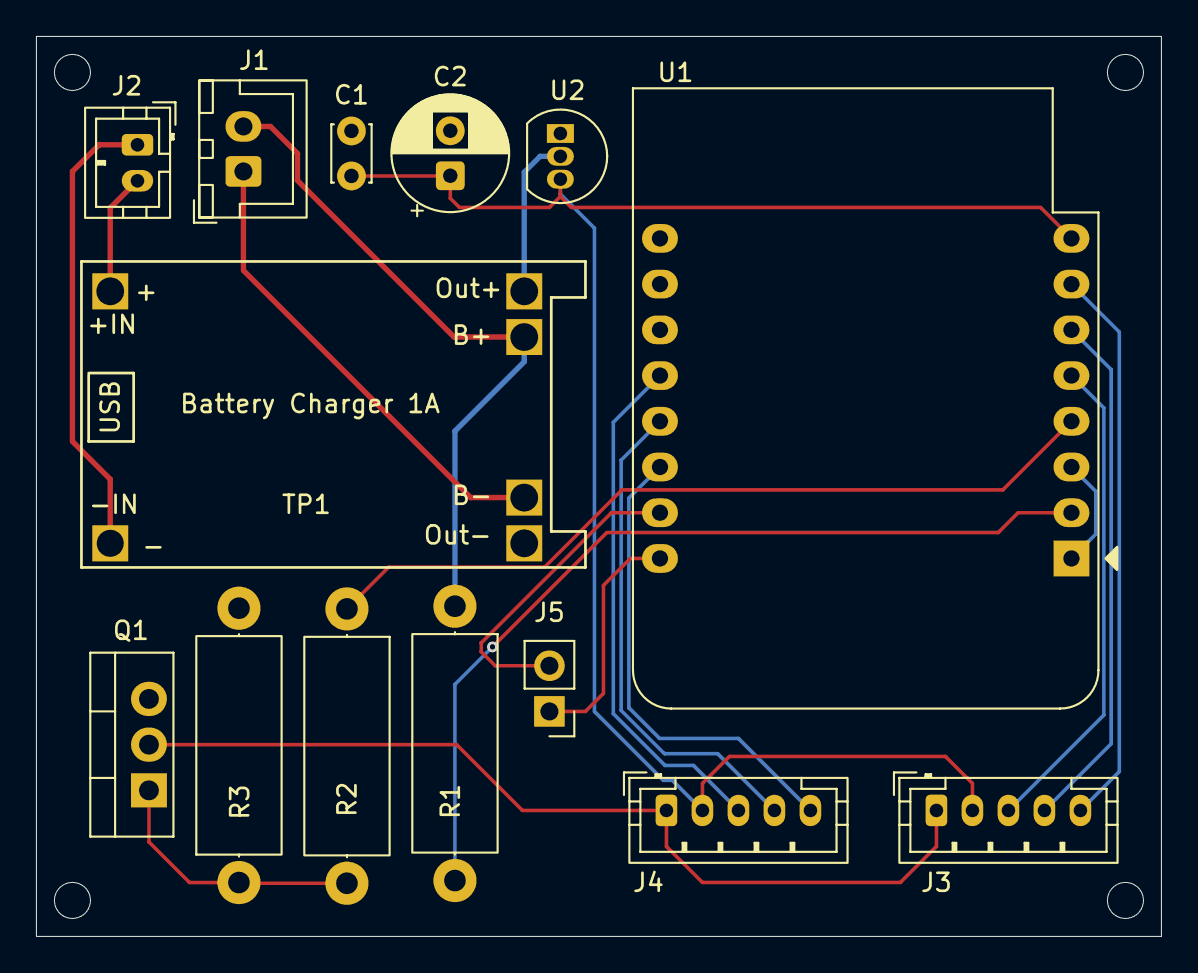
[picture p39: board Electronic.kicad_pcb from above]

Board: 2 copper layers, 62.5 x 50.0 mm, 14 parts (0 on the bottom side), 20 nets.

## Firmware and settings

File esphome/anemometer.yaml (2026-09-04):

substitutions:
  esp_name: anemometer
  esp_friendlyname: Anemometer
  esp_id: anemometer
  esp_otamode_check_interval: 5s
  esp_boot_connect_delay: 100ms
  esp_boot_connect_timeout: 30s
  esp_uptime_pub_delay: 200ms
  esp_day_sleep_min_duration_s: 120     # 2min
  esp_day_sleep_short_duration_s: 300.  # 5min
  esp_day_sleep_medium_duration_s: 900  # 15min
  esp_day_sleep_long_duration_s: 3600   # 1h
  esp_night_sleep_duration_s: 1800      # 30min
  esp_battery_percent_max: 90
  esp_battery_percent_high: 75
  esp_battery_percent_low: 30
  esp_speed_history_timeout_s: 960     # 16min
  esp_direction_history_timeout_s: 660 # 11min

esphome:
  name: ${esp_name}
  friendly_name: ${esp_friendlyname}
  comment: Wind speed measurement (D1MiniPro/TP4056/Li16650/US1881)
  on_boot:
    priority: 900
    then:
      - script.execute: start

esp8266:
  board: d1_mini_pro
  restore_from_flash: True  

# Enable logging
logger:
  baud_rate: 0 # disable to reduce power draw
  level: NONE

# Enable Home Assistant API
api:
  reboot_timeout: 0s # empeche un reboot auto si deconnection breve
  encryption:
    key: !secret anemometer_api_key

ota:
  - platform: esphome
    password: !secret ota_password

wifi:
  networks:
    - ssid: !secret wifi_ssid
      password: !secret wifi_password
      hidden: true # to prevent from scanning if connection fails
      bssid: !secret wifi_bssid #todo
      channel: !secret wifi_channel #todo
  fast_connect: True # scan disabled to reduce power draw
  post_connect_roaming: false
  power_save_mode: NONE
  min_auth_mode: WPA2
  manual_ip: # static to reduce power draw
    static_ip: X.Y.Z.T
    gateway: X.Y.1.1
    subnet: 255.255.255.0
    dns1: X.Y.1.1
  ap:
    ap_timeout: 0s # disabled to reduce power draw

#status_led: # disabled to reduce power draw
#  pin: GPIO2

sun:                        
  id: ${esp_id}_sun         
  latitude: !secret home_latitude
  longitude: !secret home_longitude

time:
  - platform: homeassistant
    id: ${esp_id}_time
    on_time_sync:
      then:
        # Update last restart time, but only once.
        - if:
            condition:
              lambda: 'return id(${esp_id}_last_restart).state == "";'
            then:
              - text_sensor.template.publish:
                  id: ${esp_id}_last_restart
                  state: !lambda 'return id(${esp_id}_time).now().strftime("%a %d %b %Y - %I:%M:%S %p");'

globals:
  - id: ${esp_id}_half_turn_pulses
    type: int
    restore_value: false
    initial_value: '0'
  - id: ${esp_id}_speed_time_history
    type: time_t[5]
    restore_value: true
    initial_value: '{0, 0, 0, 0, 0}'
  - id: ${esp_id}_speed_data_history
    type: float[5]
    restore_value: true
    initial_value: '{0.0, 0.0, 0.0, 0.0, 0.0}'
  - id: ${esp_id}_speed_history_index
    type: int
    restore_value: true
    initial_value: '0'
  - id: ${esp_id}_direction_time_history
    type: time_t[5]
    restore_value: true
    initial_value: '{0, 0, 0, 0, 0}'
  - id: ${esp_id}_direction_data_history
    type: int[5]
    restore_value: true
    initial_value: '{0, 0, 0, 0, 0}'
  - id: ${esp_id}_direction_history_index
    type: int
    restore_value: true
    initial_value: '0'

output:
  - platform: gpio
    id: ${esp_id}_power_sensors
    pin: D5

binary_sensor:
  - platform: homeassistant
    internal: True
    id: ${esp_id}_ota_mode
    entity_id: input_boolean.esphome_ota_mode
  - platform: status # for device wakeups history monitoring
    name: "Status"
  - platform: gpio
    internal: True
    id: ${esp_id}_speed_pulse_counter
    pin:
      number: GPIO12
      mode: INPUT_PULLUP
    filters:
      - delayed_on_off: 10ms
    on_press:
      - then:
          - lambda: |-
              id(${esp_id}_half_turn_pulses) += 1;
  - platform: gpio
    internal: True
    id: ${esp_id}_phase_a
    pin:
      number: GPIO4
      mode: INPUT
  - platform: gpio
    internal: True
    id: ${esp_id}_phase_b
    pin:
      number: GPIO5
      mode: INPUT

deep_sleep:
  id: ${esp_id}_deep_sleep
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

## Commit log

2026-02-20 v345 : f3d/3mf/stl update
    [Anemometre - Axe Etalon.stl, Anemometre - Couvercle Sup.stl, Anemometre - boitier.stl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]
2026-02-22 v345 : license added and stl/images updated
    [Support Helice Inf.stl, Support Helice Sup.stl]
2026-03-14 v365 : us1881+magnets supports added
    [Anemometre - Support US1881.stl, Anemometre - support aimants.stl]
2026-03-14 v365 : us1881 support updated
    [Anemometre - Support US1881.stl]
2026-03-15 v372 - us1881 support updated
    [Anemometre - Support US1881.stl]
2026-03-15 v378 - anemometer body fixed
    [Anemometre - boitier.stl]
2026-03-19 v386 : bigger drill hole for cables
    [Boite de commande - corps.stl, Liaison Anémomètre.stl, Liaison panneau solaire fixe.stl]
2026-04-03 v386 : electronix schematic added
    [Anemometre+Girouette.3mf, Electronic.kicad_pcb, Electronic.kicad_sch]
2026-04-06 v386 : electronic schematic update
    [Electronic.kicad_pcb, Electronic.kicad_sch]
2026-04-10 v386 : pcb images updated
2026-04-10 v386 : pcb size increased
    [Electronic.kicad_pcb]
2026-04-11 v386 : gerber files exported from schematic
    [Electronic-B_Cu.gbr, Electronic-B_Mask.gbr, Electronic-B_Paste.gbr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]
2026-04-11 v386 : electronic 3d model exported
    [electronic.step]
2026-04-11 v388 : 3d models linked
    [Anemometre-Electronic.f3d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]
2026-04-11 v389 : electronic schematic image added
2026-04-12 v389 : electronic pcb update
    [Electronic-B_Cu.gbr, Electronic-B_Mask.gbr, Electronic-B_Paste.gbr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]
2026-04-12 v391 : eclectronic 3d model updated
    [Anemometre-Electronic.f3d]
2026-04-14 v400 : pcb mounting supports added into control enclosure
    [Boite de commande - corps.stl]
2026-04-23 v419 : bigger drill holes for cables
    [Boite de commande - corps.stl, Liaison Anémomètre.stl, Liaison panneau solaire fixe.stl]
2026-04-23 v419 : 3mf file updated
    [Anemometre+Girouette.3mf]
2026-04-24 v441 : bigger drill holes for cables
    [Anemometre+Girouette.3mf, Boite de commande - corps.stl, Liaison Anémomètre.stl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]
2026-04-26 v441 : wind speed sensor added into esphome firmware
2026-04-26 v441 : fix resistor values on PCB
    [Electronic.kicad_pcb, Electronic.kicad_sch]
2026-05-10 v480 : Fix control enclosure for better watertightness
    [Anemometre+Girouette.3mf, Boite de commande - corps etanche.stl, Boite de commande - corps.stl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]
2026-05-10 v480 : fix anemometer cups for better low-wind sensitivity
    [Helice Sensible.stl]
2026-05-14 v494 : Switch to conical cups to improve low-wind sensitivity
    [Anemometre+Girouette.3mf, Coupelle Conique.stl, Coupelle Spherique.stl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]
2026-05-31 v514 : wind direction sensor added
    [Girouette - Pallier Aimant.stl, Girouette - boitier.stl]
2026-06-01 v514 : 3mf file updated
    [Anemometre+Girouette.3mf]
2026-07-16 v535 : wind direction sensor support
    [Anemometre+Girouette.3mf, Cage roulement libre.stl, Girouette - Corps 2.stl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]
2026-07-19 v543 : both wall support and weathervane variants added
    [Girouette - Variante.stl, Liaison Mur - Variante.stl]
2026-07-20 v543 : wall support variant updated
    [Anemometre+Girouette.3mf, Liaison Mur - Variante.stl, Pallier roulement.stl]
2026-07-22 v556 : wall support variant updated
    [Anemometre+Girouette.3mf, Liaison Mur - Variante.stl]
2026-07-24 v558 : wall support variant updated
    [Anemometre+Girouette.3mf, Liaison Mur - Variante.stl]
2026-10-11 v582 : as5600 sensor support added
2026-10-11 v582 : 3mf print file updated
2026-10-25 v597: esphome firmware/print project updated
